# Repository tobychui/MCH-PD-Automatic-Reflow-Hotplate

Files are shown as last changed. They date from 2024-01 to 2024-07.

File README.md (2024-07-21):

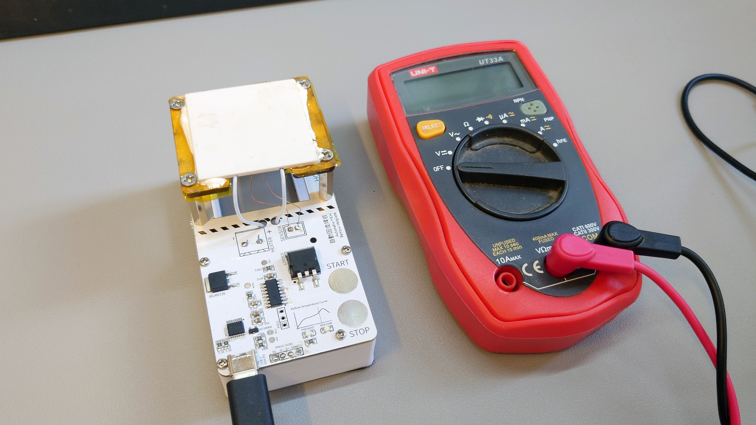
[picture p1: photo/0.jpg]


# MCH PD Powered Reflow Hotplate

A palm sized MCH (Metal Ceramic Heater) based reflow hotplate powered by USB-PD      

This is a DIY, low cost PD powered reflow hotplate that uses metal ceramic heater (MCH) instead of PCB hot plate for heating. It features a USB type C input port that can be powered by a 60W (65W) PD power supply at 20V 3A. This hotplate can automatically reflow mid-temperature range solder paste like Sn63Pb37. What you need is press and hold  the START button for 5 seconds and wait for the reflow process to finish.

### Features

- USB type C PD Powered (no special power adapter or dangerous AC power required)
- Budget & High quality heating element (instead of PCB hotplate)
- Open Source
- Fully automatic, just hold and press "START" and wait for the reflow to complete

## Ready to Use Hotplate
You can get a prototype from my [Tindie store](https://www.tindie.com/products/tobychui/tobys-automatic-mch-pd-reflow-hotplate/) 

## Quick Start

1. Power up your reflow hotplate with 60W or above PD charger (PD power bank works as well)
2. After the MCU boots up, the yellow LED should blink slowly, indicating it is ready
3. Place your PCB to be reflow on top of the white MCH module
4. Press and hold the START touch button until the yellow LED start fast blinking
5. Wait until the hotplate automatically complete the reflow process.  After the reflow is done, you will see the red light blinking slowly.
6. Carefully remove the completed PCB away from the MCH module. Press  STOP to reset the hotplate and it is ready for the next reflow cycle.

### Reflow Stages

| Stages | LED Status | Meaning |
| --- | --- | --- |
| 1 | Yellow Slow Blinking | System Ready |
| 2 | Yellow Fast Blinking | Automatic Reflow starting in 5 seconds |
| 3 | Yellow ON | Heating to soaking temperature (<150 °C) |
| 4 | Red Fast Blinking | Soaking (150 - 180 °C) |
| 5 | Red ON | Reflowing (220 °C) |
| 6 | Red Slow Blinking | Reflow completed. Remove PCB now |

After stage 6 is completed and you have removed the PCB from the  hotplate, press STOP once to reset the stage to 1. You can also press  STOP anytime you think it is suitable, including early stopping if your  PCB is small and do not require that much temperature in the reflow  stage.

## Desolder Mode
This mode was added since the v6 revision of the hotplate. **Older version of the hotplates are not compatible with this new firmware.**

In case you want to desolder something that you misplaced or recover components from damaged PCB, you can press and hold "START" + "STOP" for 5 seconds until the yellow LED start fast blinking. 
Then the reflow hotplate will enter desolder mode and keep at reflow temperature for 5 minutes.

## Specifications

| properties | Value |
| --- | --- |
| Controller | CH552G (Arduino Programmable) |
| LEDs | Yellow(Preheat / Soaking), Red(Reflow) |
| Dimension (Without Base, W x L x H) | 54mm * 102mm * 30mm |
| Dimension (Assembled, W x L x H) | 54mm * 102mm * 48mm |
| Heat-plate Size | 40mm * 40mm (± 1mm) |
| Require External Programmer | No (USB programming pins exposed as 2.54 pads) |
| Power Input | USB type-C PD 20V 3A (60W / 65W PD power supply recommended) |
| Power Consumption | 30 - 50W (Depends on reflow stage) |
| USB Connector | USB type C |
| Solder Paste | Sn63Pb37 (Reflow profile editable in source code w/ Arduino IDE) |

## Gallery 
### v2 Hotplates (Original)
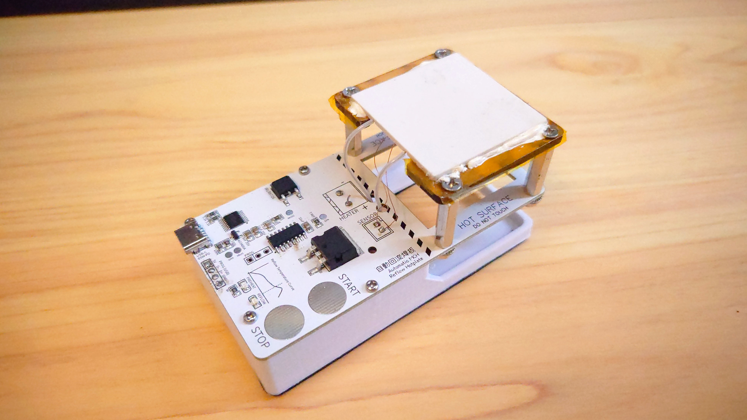
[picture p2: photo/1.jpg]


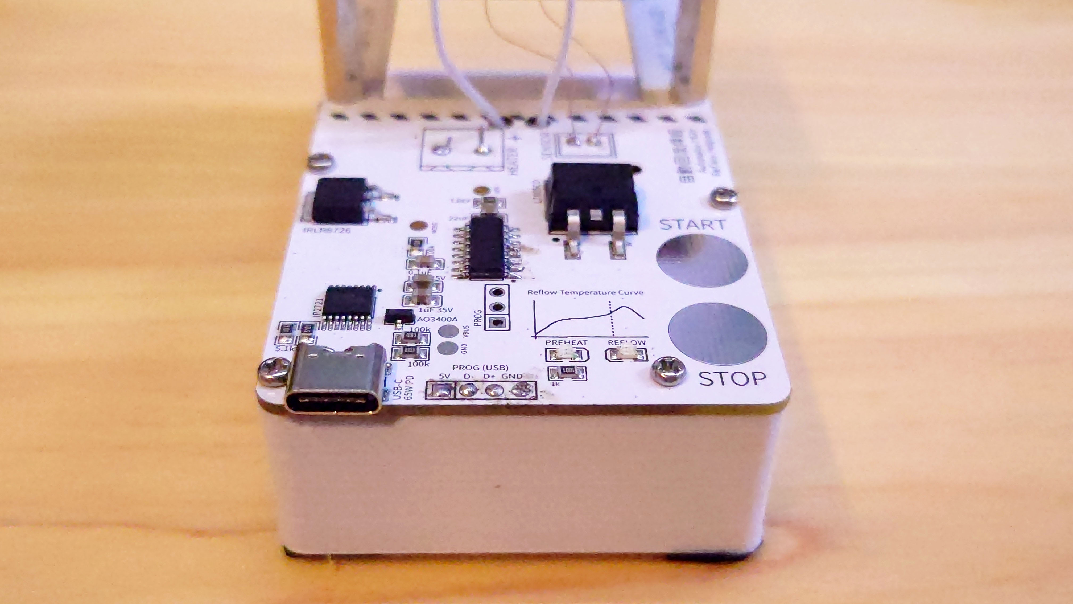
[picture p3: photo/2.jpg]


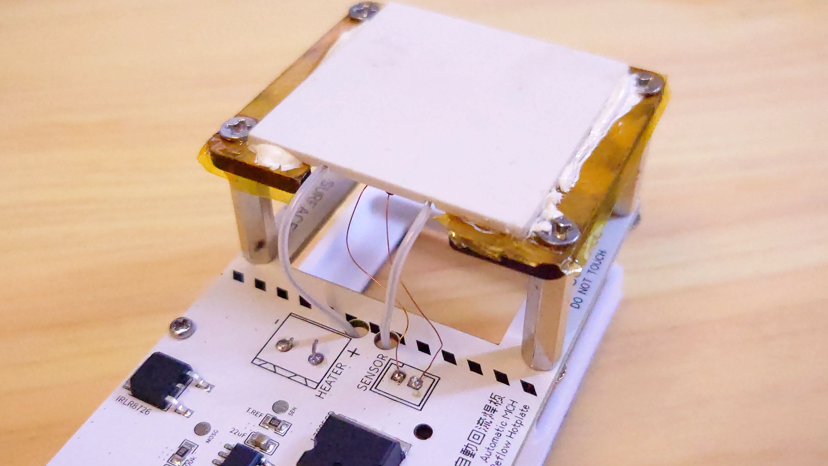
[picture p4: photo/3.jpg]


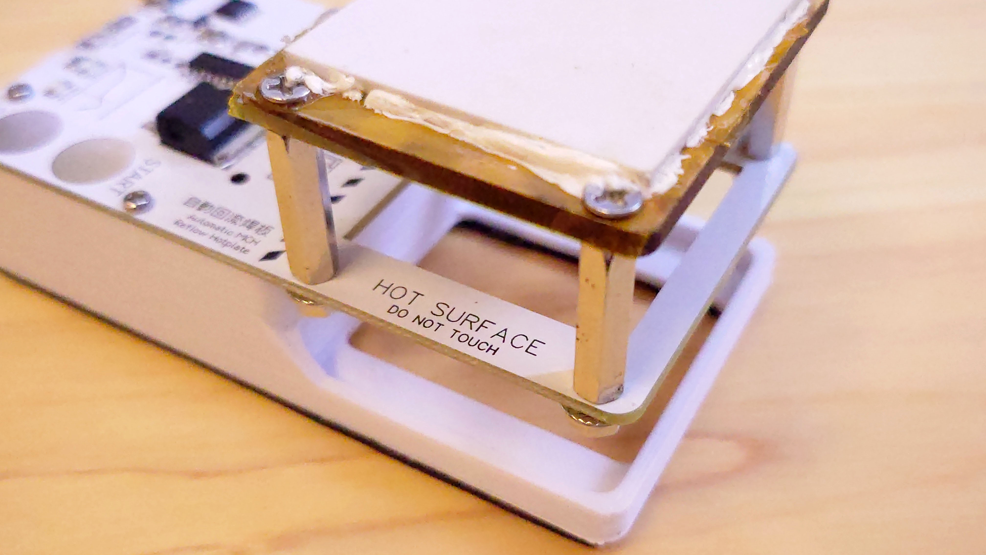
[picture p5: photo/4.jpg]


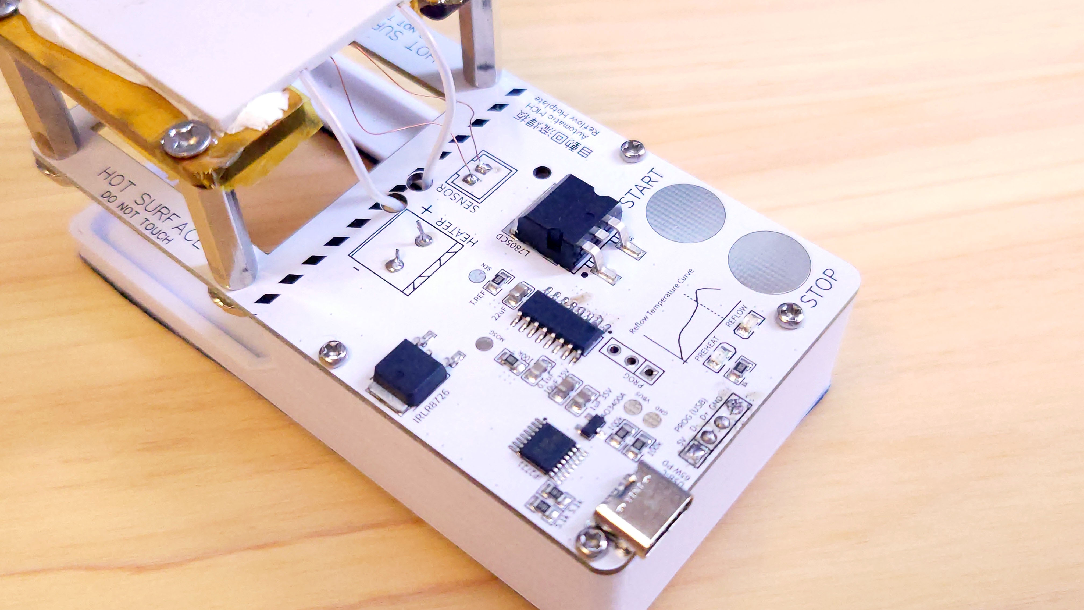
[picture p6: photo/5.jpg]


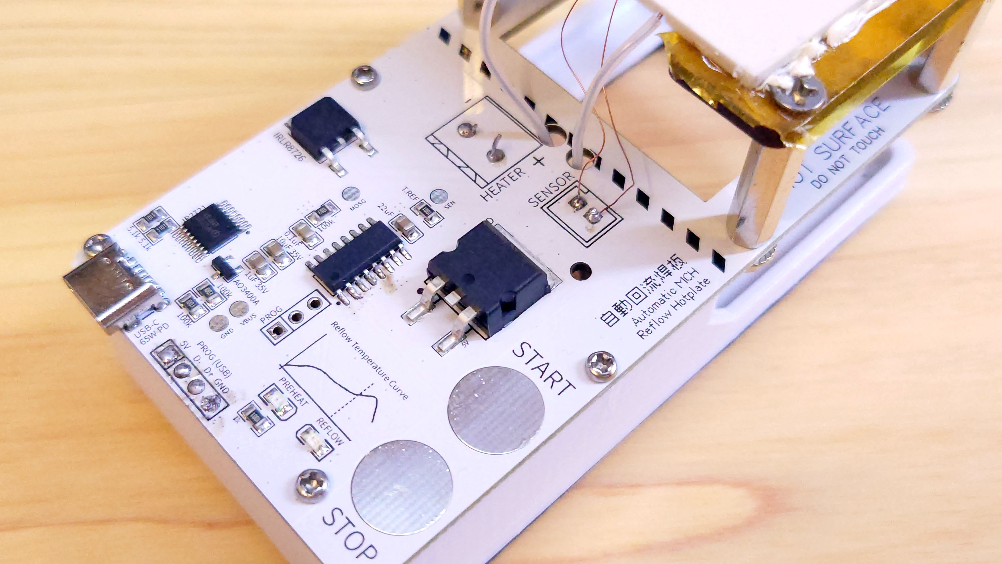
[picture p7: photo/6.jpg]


### v6/7 Hotplates
title

See more over [here](https://github.com/tobychui/MCH-PD-Automatic-Reflow-Hotplate/wiki/Introduction-to-the-v6-Hotplate!)

## Programming

### Programming Interface

1. The PCB contains a 2.54x4 pins labeled PROG (USB) with 5V, D+, D- and GND. This is a standard USB 2.0 connector as CH552G has build in USB hosts mode that do not require a USB to UART converter chip. Solder a USB male header at this location following the pins label written on the silkscreen.

2. There are another 2.54 x 3 pins also labeled PROG on the left 2 pins of the 3 pins. It is for forcing the CH552G into USB programming mode. If you want to re-program the reflow hotplate, bridge the two left most pins (the two pins closer to the LED) of the 2.54x3 and connect the USB pins to your computer. Otherwise, you can bridge the right-2 pins or leave all 3 pins unconnected.

### Flashing (Downloading) New Firmware

The timing for downloading the firmware are critical to the success of firmware download. Please follow EXACTLY on how to flash the firmware with the steps below.

#### Serial Mode

1. After you have finish changing the code in the firmware, select "16Mhz (internal, 3.3V or 5V)" in the "Clock Source" menu. For upload method, select "Serial"
2. Insert the hotplate's USB port into your computer. A new COM port should pops up. Select that newly pop-up COM port as download target
3. Click the Download button in your Arduino IDE

#### USB Mode

In case the Serial mode is not working due to some driver conflict or Windows bug, you can optionally choose USB upload mode

1. After you have finish changing the code in the firmware, select "16Mhz (internal, 3.3V or 5V)" in the "Clock Source" menu. For upload method, select "USB"
2. Click the Download button in your Arduino IDE
3. At the same time of doing step 2, bridge the left-two PROG pins from the 2.54 x 3 header, and quickly insert the USB port into your computer's USB port (timing is important)
4. Just before the Arduino IDE starts to upload, un-bridge the left-two PROG pins from the 2.54 x 3 header. If you keep them bridged, the Arduino IDE will freeze during upload and after a few seconds report upload failed due to timeout.
5.  If timing is correct, you will see the Arduino debug console says upload completed
6. If you un-bridge it too early, you will see a new COM device pops up. You will need to unplug the device, short the left-two PROG pins again and repeat step 3 - 4.

### Notes

- If you encounter issues with yellow LED not light up when powered up / unstable touch buttons / lower than expected peak reflow temperature,  please make sure you are using a high quality PD power supply and cables that is designed for 60W or above.

- The reflow temperature is intentionally set higher than the expected  temperature of 230 degree celcius to make up for the lose in heat to the surrounding. You can perform early-stopping if the reflow is completed  but the hotplate is still heating up.

## License

CC BY-NC-SA

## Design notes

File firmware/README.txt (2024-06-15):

For PCB versions before 6 (v1 - v5), use the reflow.ino firmware.
For PCB versions 6 or above, use the reflow-v6 firmware.

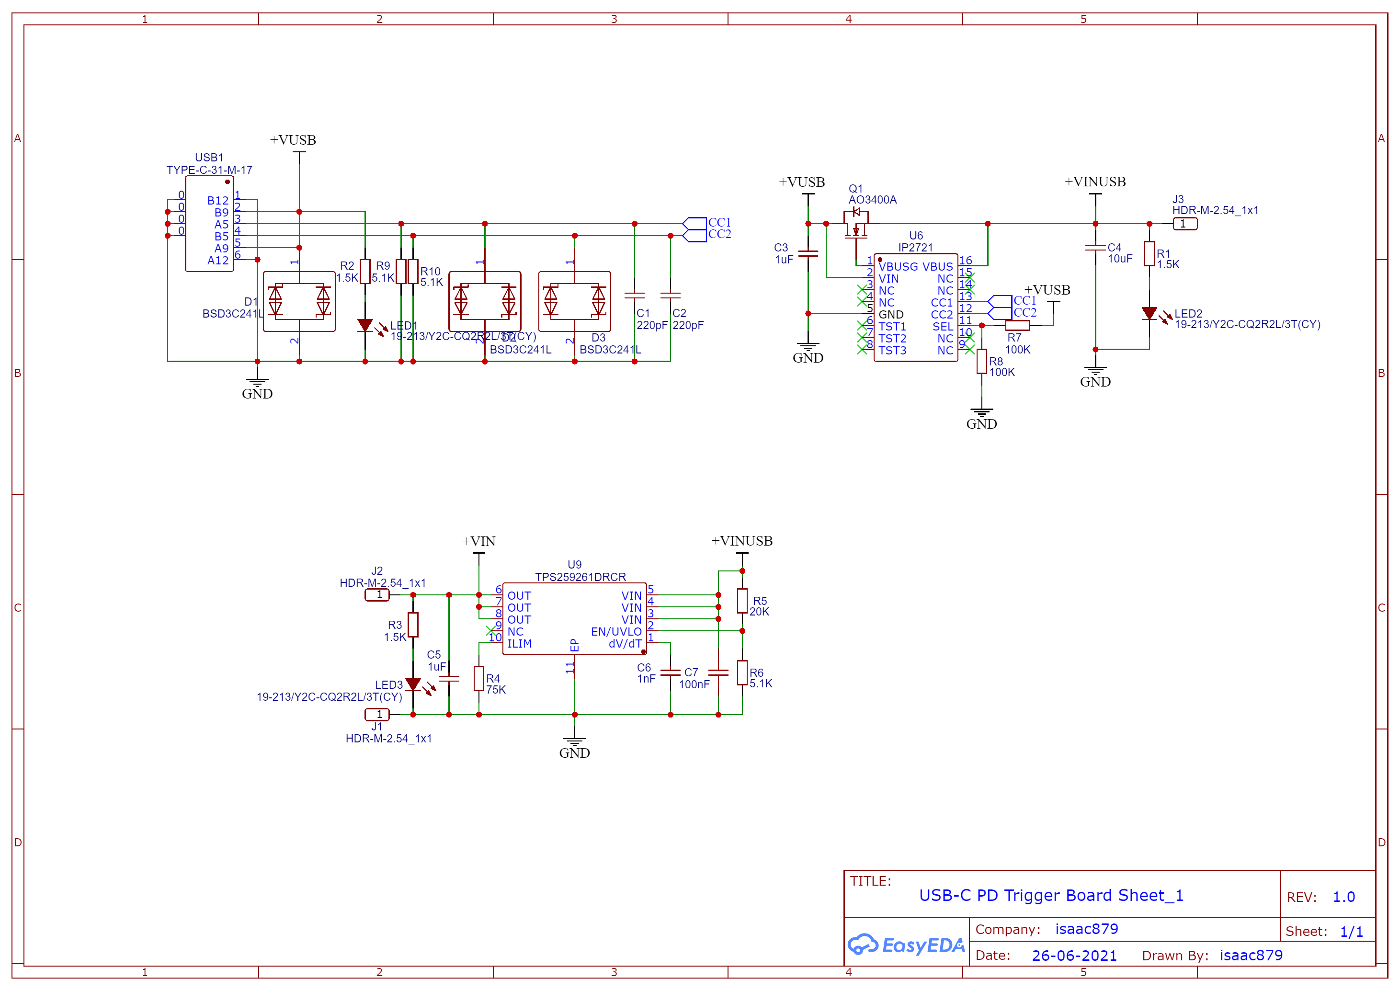
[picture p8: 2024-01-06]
schematic/IP2721.png

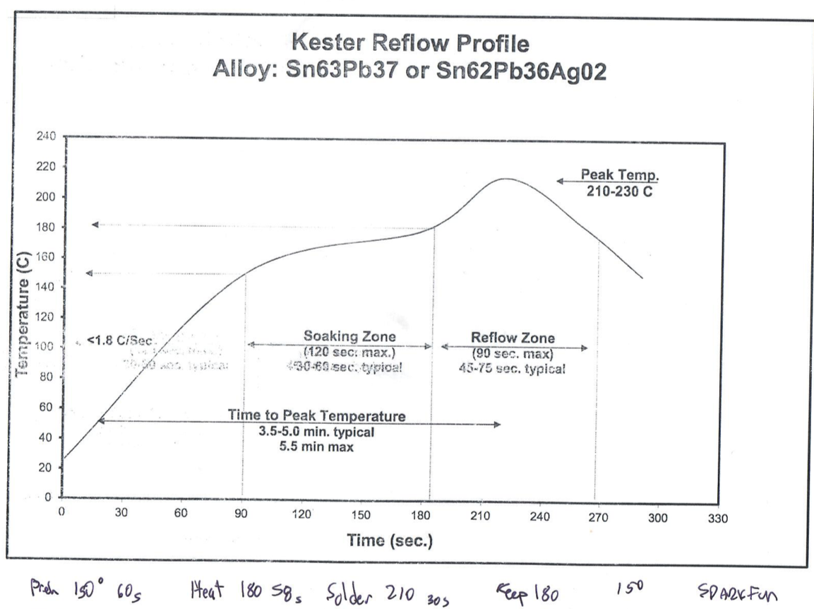
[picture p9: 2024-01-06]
schematic/Reflow curve.png

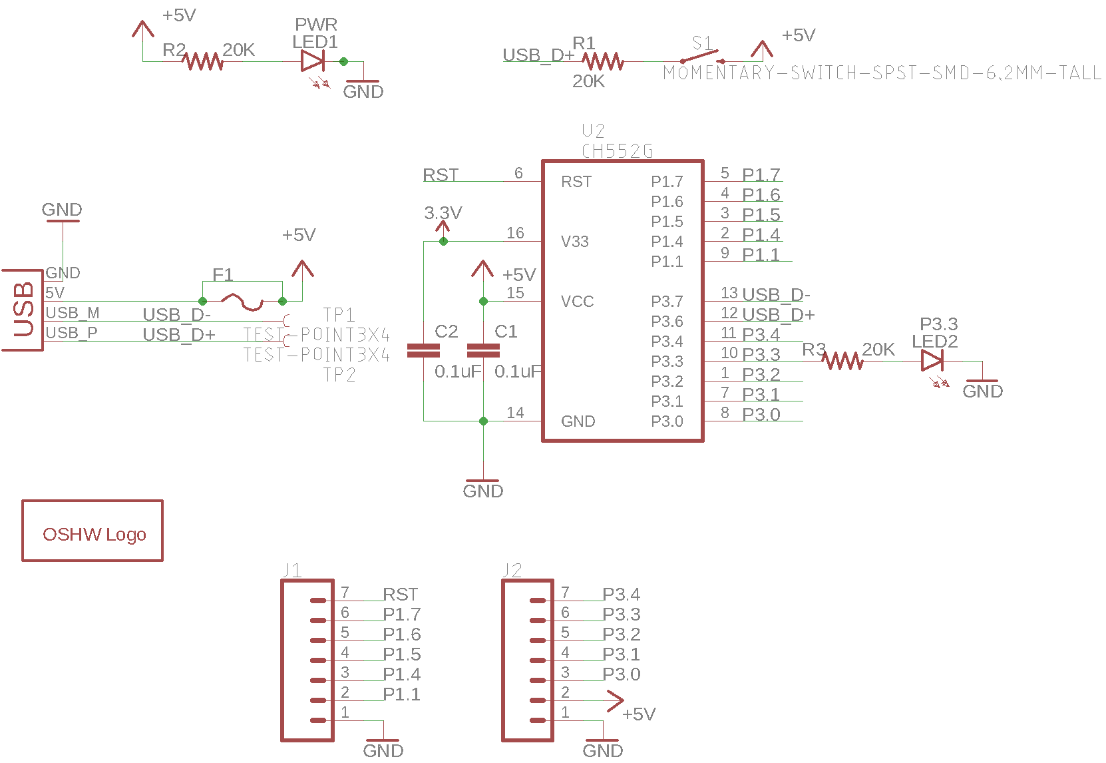
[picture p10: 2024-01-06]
schematic/CH552G.png

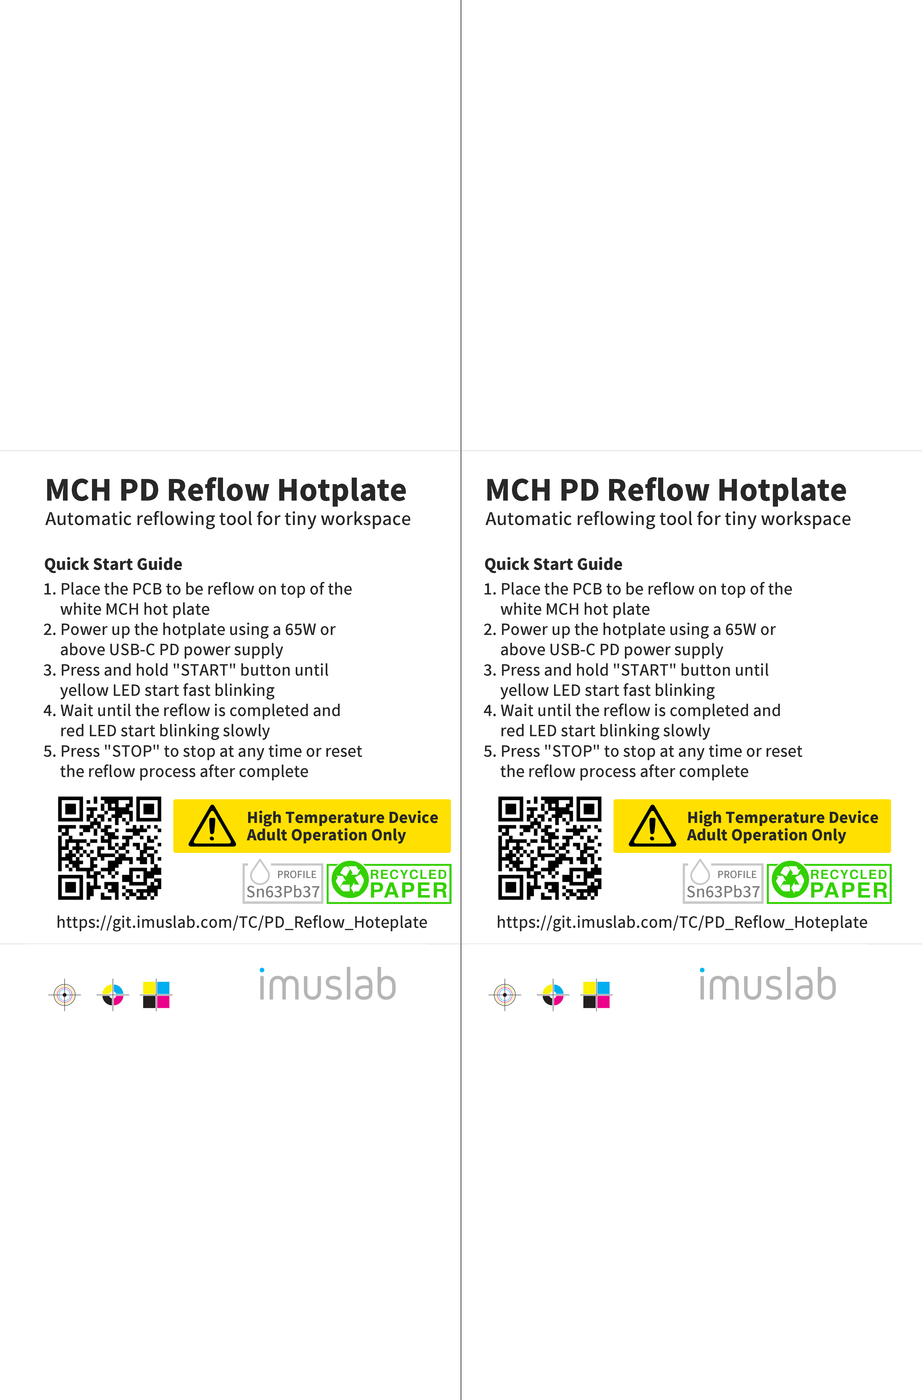
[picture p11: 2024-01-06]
package/package.png

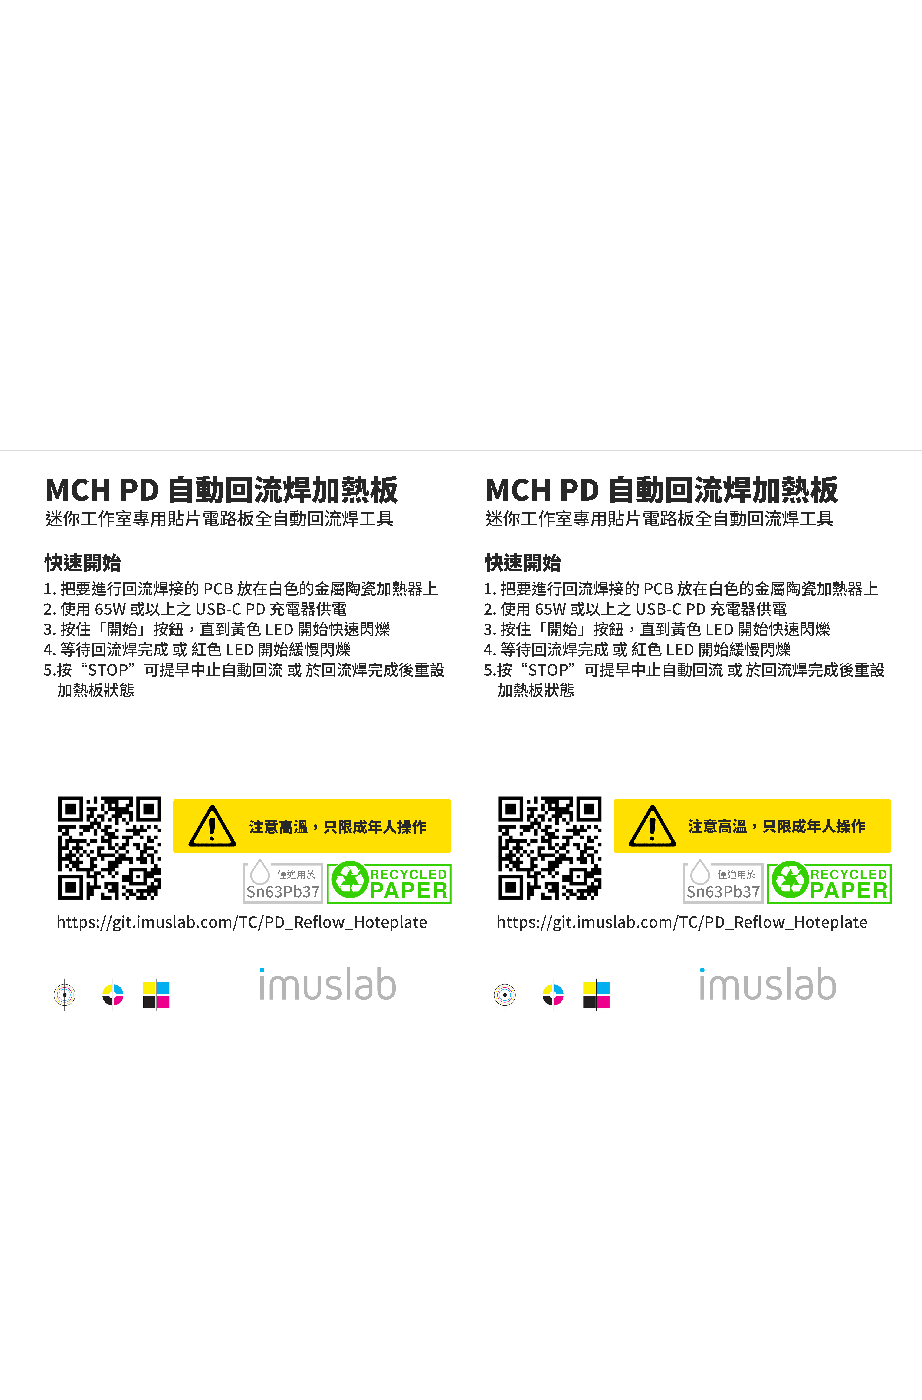
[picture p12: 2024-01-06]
package/package-zh.png

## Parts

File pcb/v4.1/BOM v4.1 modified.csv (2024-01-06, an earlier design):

ID | Name | Designator | Footprint | Quantity | Manufacturer Part | Manufacturer | Supplier | Supplier Part | Price
1 | L7805CD2T | U5 | TO-263-2_L10.0-W9.2-P2.54-LS14.2-BL | 1
2 | IRLR8726T | U7 | TO-252-3_L6.5-W5.8-P4.60-LS9.9-BR | 1
3 | HDR-TH_4P-P2.54-V-F | PROG1 | HDR-TH_4P-P2.54-V-F | 1
4 | CL21A106KAYNNNE | C1 | C0805 | 1
5 | CL21B105KBFNNNE | C2 | C0806 | 1
6 | C45783 | C5 | C0807 | 1
7 | KT-0805Y | LED1 | LED0805-R-RD | 1
8 | CONN-TH_XH2.54-2P | SENSOR | CONN-TH_XH2.54-2P | 1
9 | 0805W8F5101T5E | R1,R2 | R0805 | 2
10 | 0805W8F1003T5E | R4,R5,R6 | R0805 | 3
11 | 0805W8F1001T5E | R8,R9 | R0805 | 2
12 | CONN-TH_2P-P5.00_WJ500V-5.08-2P | P1 | CONN-TH_2P-P5.00_WJ500V-5.08-2P | 1
13 | HDR-TH_3P-P2.54-V-F | H1 | HDR-TH_3P-P2.54-V-F | 1
14 | NCD0805R1 | LED3 | LED0805-RD_RED | 1
15 | CC0805KRX7R9BB104 | C3 | C0805 | 1 | 0.1uF/100V | null
16 | C20917 | U4 | SOT-23-3_L2.9-W1.3-P1.90-LS2.4-BR | 1
17 | IP2721 | U1 | TSSOP-16_L5.0-W4.4-P0.65-LS6.4-BL | 1 | IP2721 | INJOINIC(英集芯) | LCSC | C603176 | 0.811
18 | TYPE-C 6P | USB-C | TYPE-C-SMD_TYPE-C-6P | 1
19 | CH552G | U3 | SOP-16_L10.0-W3.9-P1.27-LS6.0-BL | 1 |  |  | null

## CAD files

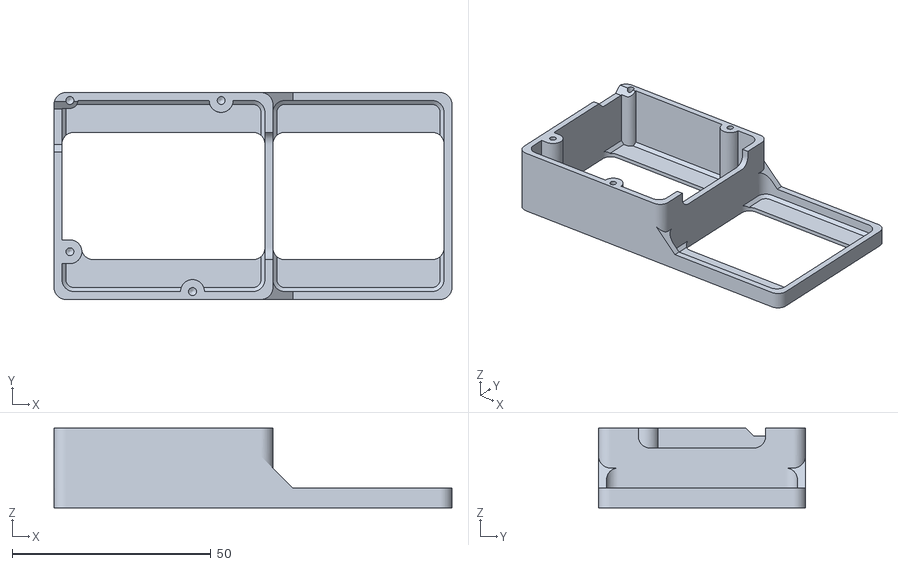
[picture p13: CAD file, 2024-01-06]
model/base.stl
100.0 x 52.0 x 20.0

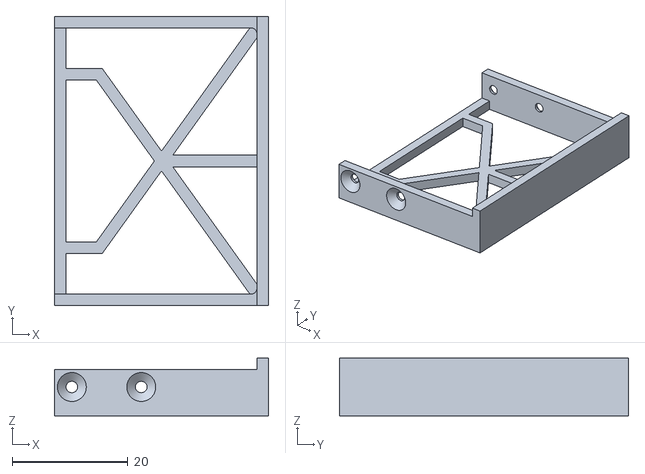
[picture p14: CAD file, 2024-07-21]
PCB_support/face-1.stl
37.0 x 50.0 x 10.0

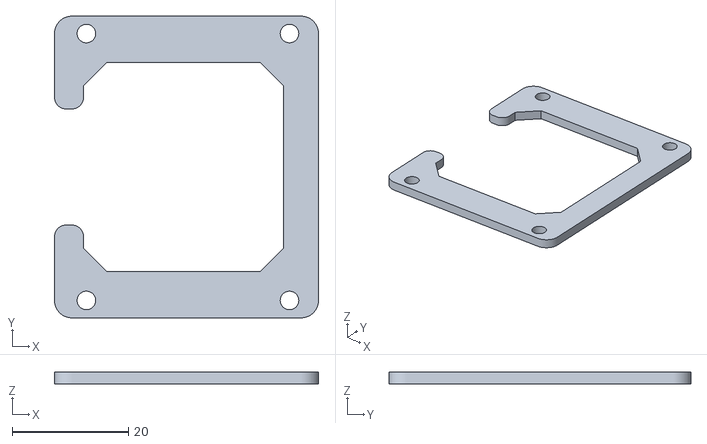
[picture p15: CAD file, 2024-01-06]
model/wood_supp.stl
45.5 x 52.0 x 2.00

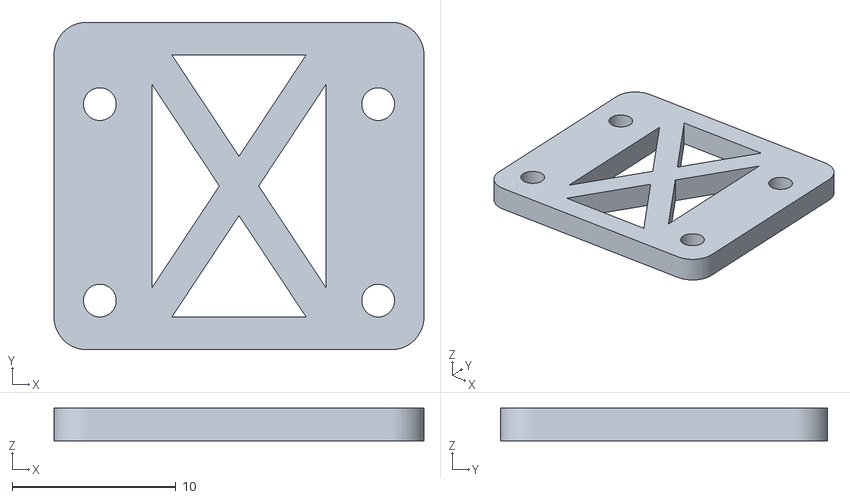
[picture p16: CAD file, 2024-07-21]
PCB_support/face-2.stl
22.6 x 20.0 x 2.00

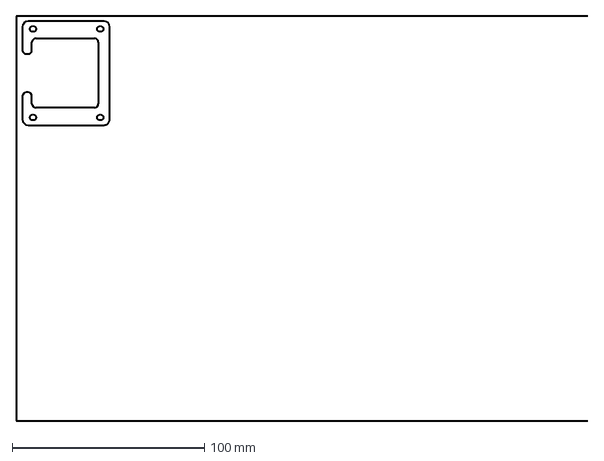
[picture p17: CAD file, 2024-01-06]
model/wood_suppv2.dxf
297.0 x 210.0 mm

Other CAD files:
PCB_support/face-1.ipt
PCB_support/face-2.ipt
PCB_support/test-fit.iam
model/base.ipt
model/wood_suppv2.dwg
model/wood_suppv3.ipt

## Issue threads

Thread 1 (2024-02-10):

Documentation for Reprogramming is vague in some places

dirkruiken, 2024-02-10:
Hi -

I was trying to reprogram the board and had trouble with the documentation. Can you add which board type you select in the Arduino IDE (and what source you are using if that is a custom board definition)?
Also for the USB flashing description, is the board already powered up with the usb-c connector when I add the jumper & insert the programmer usb cable? If it was not powered up yet, adding the jumper and plugging usb programmer in at the same time would be the same as first applying the jumper to the unpowered board and then plugging it in, no?

Thanks, Dirk

tobychui, 2024-02-14:
Hi @dirkruiken , thanks for the wait. It is Lunar New Year holiday here in Taiwan and I didn't check Github for a few days.

Have you read the hackaday post regarding the usage and assembly of the MCH hotplate before purchase? If no, here is the [link](https://hackaday.io/project/194305-diy-usb-pd-powered-mch-automatic-reflow-hotplate).

In simple words, you will need to install the ch55x arduino library and select CH552 as the target board for uploading your code. The board library can be downloaded [here](https://github.com/DeqingSun/ch55xduino).

The usb-C connector is not for programming. It is for PD power only. To program it, use the 4 pin 2.54 header labeled USB (5V, D-, D+ and GND) by connecting a USB male header to it and insert it into your computer. The firmware should have an emulated USB serial device which you can directly program via Arduino IDE by selecting the targeted COM port (or tty if you are using Linux) in Serial upload mode. So if you see a COM port pop up after you inserted the hotplate to your computer, you do not need to bridge the jumper for entering the USB upload mode.

If you have difficulties flashing the chip, you can refer to the ch55xduino repo for detailed information. The MCH hotplate MCU portion of the circuit is basically based on Deqing Sun's design so all instruction on his repo are applicable to this device as well.

Feel free to tag me and add a comment if you need further help :)

tobychui, 2024-02-17:
Closing issue as no follow up questions were asked.

Closed 2024-02-17.

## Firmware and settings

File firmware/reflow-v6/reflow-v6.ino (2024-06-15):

/*
   60W PD Powered Automatic Reflow Hoteplate
   Author: tobychui

   Firmware version for v6 or above PCB
   
   Notes:
   - Temperature sensing is done using 1k 1% resistor and a 100k Thermistor
     You might need to change the code if you are using other values
   - If you are using the type-C 6p version of the reflow PCB, and after
     pluggin in the type C cable no led lights up, try flip the type C
     cable upside down

   Button Mappings (Active Low, aka not pressing = HIGH)
   Start Btn: P1.4
   Stop Btn: P1.7

   Download Settings
   CH552
   16Mhz (internal, 3.3V or 5V)
*/
#include <Serial.h>

/* Hardware Definations */
#define TEMP_PIN 11     //P1.1
#define HEATER_PIN 34   //P3.4
#define LED_PREHEAT 15  //P1.5
#define LED_REFLOW 16   //P1.6
#define START_BTN 14    //P1.4
#define STOP_BTN 17     //P1.7

/* Software Definations */
//Timing settings. Each cycle is approximately 100ms
#define HOLDSTART_TIME 30           //START Button hold down time in cycles
#define HOLDSTOP_TIME 10            //STOP Button hold down time in cycles
#define SOAKING_TIME 600            //SOAKING temperature upkeep time in cycles
#define MAX_CONTINUE_OPR_TIME 3000  //MAX_CONTINUE_OPR automatic shutdown desolder heatbed if continue operate for ~5 minutes for safty reasons
/*
   Temperature Settings

   The ADC value can be calculated using the following line equation
   t=-0.7x+250

   where X is ADC reading and t is target temp in degree C

   Note that different setup (e.g. ref resistor value / NTC resistor value) might have different equations
   You can experiment with yours and get a few data point to plot your own line
*/
#define COOLDOWN_TEMP_ADC 255  //Room temperature
//Preheat temp & power
#define PREHEAT_START_ADC 143  //150 degree C
#define PREHEAT_TEMP_ADC 122   //160 degree C
#define PREHEAT_PWR_PWM 155    //60% power output
//Reflow temp & power
#define REFLOW_TEMP_ADC 58  //220 degree C
#define REFLOW_PWR_PWM 255  //100% power output
//Overheat cutoff temp
#define CUTOFF_TEMP_ADC 53  //250 degree C

/* Function Prototypes */
bool updateHeaterPowerState();
void updateKeyStates();
void handleLEDBlinking();
void handleReflowProcedures();
void handleDesolderProcedures();
void enterStandbyMode();
int readTemp();


/* Runtime Variables */
bool reflowing = false;       //Reflow has started
bool reflowComplete = false;  //Indicate if the stopping is done because of reflow complete
bool startPressed = false;    //Start button is pressed down
bool stopPressed = false;     //Stop button is pressed down

/*
  Reflow Stages define what is the next state the hotplate should reach
  0: Standby
  1: Preheating
  2: Preheat Holding / Soaking
  3: Reflowing
  4: Cooling down

  10: Preheating to reflow temp for desoldering
  11: Desolder Mode (Keep at REFLOW_TEMP_ADC)
*/
int reflowStages = 0;
int startCountdown = HOLDSTART_TIME;  //Hold for HOLDSTART_TIME to start to prevent accidental touches
int stopcountdown = HOLDSTOP_TIME;    //Hold for HOLDSTOP_TIME to stop reflowing
int cycleCounter = 0;                 //Record cycle time up to 10 seconds
int soakingCountdown = SOAKING_TIME;
int desolderCountdown = MAX_CONTINUE_OPR_TIME; //Prevent overheat

//Blink state controls
bool blinkState = false;  //If blinking this will be switching between true and false
bool blinkYellow = true;  //Slow blink yellow if enabled (Standby). Do not enable both yellow and red at the same time
bool blinkRed = false;    //Slow blink red if enable (End of Reflow). Do not enable both yellow and red at the same time
bool fastBlinkState = false;
bool fastblinkRed = false;


//Real-time temperature control targets
int targetTempADC = 255;  //Target ADC reading to reach, 255 = room temperature
int targetPwrPWM = 0;     //Target PWM cycle for heater, 255 = full power, 0 = off
int offset = 0;           //Allow +-offset for the ADC reading before reheating / cooling

void setup() {
  //Set button pins to input
  pinMode(START_BTN, INPUT);
  pinMode(STOP_BTN, INPUT);

  //Set LED pins to output
  pinMode(LED_PREHEAT, OUTPUT);
  pinMode(LED_REFLOW, OUTPUT);
  digitalWrite(LED_PREHEAT, LOW);
  digitalWrite(LED_REFLOW, LOW);

  //Set temp sense pin to input
  pinMode(TEMP_PIN, INPUT);

  //Set mosfet control pins to output and disable it
  pinMode(HEATER_PIN, OUTPUT);
  digitalWrite(HEATER_PIN, LOW);

  USBSerial_println("Reflow Hotplate Ready!");
}


void loop() {
  /* State Check */
  updateKeyStates();

  /* Main reflowing logics */
  //Add delay to the end of each conditions so each loop cycle is approximate 100ms
  if (reflowing && reflowStages < 10) {
    //Automatic Reflow
    handleReflowProcedures();
  } else if (reflowing && reflowStages >= 10) {
    //Desolder hotplate
    handleDesolderProcedures();
  } else {
    /* Standby Mode */
    digitalWrite(HEATER_PIN, LOW);
    blinkYellow = true;
    delay(100);  //adjust this if needed to make sure reflow cycles use the same time as standby cycles
  }

  /* Blink Signal Handlers */
  handleLEDBlinking();

  /* 
    Cycle Counter 
    Counter are limited to 600 to prevent overflow.
  */

  cycleCounter++;
  if (cycleCounter > 600) {
    cycleCounter = 0;
  }
}

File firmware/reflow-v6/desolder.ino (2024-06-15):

/* desolder.ino handles desoldering (aka just a basic heated plate) procedures */

void handleDesolderProcedures() {
  bool tempReached = updateHeaterPowerState();  //This take around 100ms
  if (reflowStages == 10 && tempReached) {
    //Temperature reached. Stop red blinking and light up red light
    fastblinkRed = false;
    digitalWrite(LED_REFLOW, HIGH);
    desolderCountdown = MAX_CONTINUE_OPR_TIME;  //Start counting down max operation time
    reflowStages = 11; //Move to consistent heating mode
  }

  if (desolderCountdown == 0) {
    enterStandbyMode();
    desolderCountdown = 0;  //Prevent underflow
  }
  desolderCountdown--;
}

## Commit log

2024-01-06 init commit
    [600_300_3.ipt, 600_300_3x35.0003.dwg, 600_300_3x35.dwg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]
2024-01-06 Clean up old data
    [600_300_3.ipt, 600_300_3x35.0003.dwg, 600_300_3x35.dwg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]
2024-05-24 Added v6 design
    + Added v6 gerber and source file (wip)
    [BOM v4.1 modified.csv, PickAndPlace_PCB_Reflow Hotplate v4_2023-10-31.csv]
2024-06-15 Added v6 and v7 PCB and firmwares
2024-07-21 Added PCB supporter 3D Model
    - Added PCB supporter 3D model for reflowing larger than hotplate size PCB
    [face-1.ipt, face-1.stl, face-2.ipt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]
